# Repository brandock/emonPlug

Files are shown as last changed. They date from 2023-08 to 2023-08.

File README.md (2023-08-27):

# emonPlug Overview
OpenEnergyMonitor-compatible energy monitoring US plug. 

emonPlug is an energy monitoring transmitter unit that can monitor AC electrical consumption of one appliance connected to its NEMA 5-15R receptacle. 

emonPlug is designed to be used together with an emonBase web-connected base station from OpenEnergyMonitor. It can be thought of as an emonTx+emonVs for monitoring one appliance.

Make sure to read the warning and disclaimer below before starting any work on emonPlug assembly or use. 

# emonPlug Architecture
emonPlug uses a CT to perform non-invasive current monitoring, similar to emonTx from OpenEnergyMonitor. https://docs.openenergymonitor.org/emontx3/index.html

It uses a voltage transformer for voltage monitoring and includes a built-in power supply, similar to emonVs from OpenEnergyMonitor. https://docs.openenergymonitor.org/emontx4/voltage_sensors.html

It is firmware compatible with emonTx3 (with appropriate calibration settings). emonPlug-specific firmware, based on the emonTx3 firmware, is provided in this repository.

To use emonTx34_CM firmware change the following settings:

float vCal_USA = 111.686;  
float i1Cal = 14.68;                                       
float i1Lead = 7.6;

bool  USA=true;

The emonPlug-specific firmware omits CTs 2, 3, and 4 and provides a more detailed packet for CT1: Vrms, Irms, PowerFactor, Frequency, LogPeriod, RealPower, ApparentPower, WattHours.

# emonPlug Parts
The CT is an AC1015 from Talema Group. It is rated to 15A with 1000:1 turn ratio. https://talema.com/wp-content/uploads/datasheets/AC.pdf

The voltage transformer is the ZMPT101B. This is the same transformer used in the emonVs. The current emonPlug is US-specific, so the 3x10K, 1/4W current-limiting resistors are designed to maximize the waveform of 120V AC. More resistance, more power dissipation, and a different burden resistor would be necessary for anyone modifying emonPlug for use with 240V AC outside the US.

emonPlug uses the Polycase PM2425 AC wall plug enclosure with US 15 AMP 120 VAC plug configuration. https://www.polycase.com/pm2425.

The emonPlug MCU is the Microchip ATMega328 and the radio is the HopeRF RFM69CW, similar to emonTx3.

# emonPlug Photos

emonCMS_output

pm2425




# Warning and Disclaimer
Make sure to read this disclaimer before starting any work on emonPlug assembly or use. Credit to Felix Rusu of LowPowerLab for the wise wording of this advice and disclaimer.

emonPlug is isolated from mains electricity via the RECOM PSU (3kV isolation). Additional safety devices in the emonPlug include a current limiting fuse and a MOV (metal oxide varistor) device to help protect against transients.

Electricity WARNING: whenever you touch anything that is or was connected to mains voltages you have to really know what you are doing, otherwise you may shock yourself to shivers. If you are not 100% sure, do yourself a favor and don’t touch anything. ATX power supplies, TVs, CRT/LCD monitors, among most other high voltage devices contain very large capacitors that can hold lethal charges that may or may not discharge after the device is unplugged. You should discharge these caps before touching the circuit.

You should not attempt to assemble or use an emonPlug if you are not familiar with mains wiring! Mains voltage can cause a fatal shock or start a fire when used improperly or negligently! Please consult this electrical safety handbook to understand how you can protect yourself and your equipment from electrical shock.

The emonPlug is not an end consumer product but an open-source design that requires assembly/soldering and is intended for users comfortable/qualified to assemble it. Certain parts are polarized and require proper orientation before soldering otherwise emonPlug may malfunction or not work.
emonPlug also requires programming prior to it being functional. The designer of emonPlug is not liable for how the end user decides to assemble or use and customize the sample firmware code. The information and sample code is meant as an educational resource only, to help guide the end user with assembly and better understand how emonPlug can operate. The end user is fully responsible to ensure the final product will be electrically safe to operate.
Although as a whole, emonPlug is not UL/CSA/CE certified. It uses a certified power supply. However emonPlug comes with NO GUARANTEES expressed or implied and the designer is not liable for any injuries or damage caused by improper assembly or use of emonPlug. It may be against code to install non UL certified equipment in your area, so you are responsible to make sure you are compliant or take any risks on your own. If you do not agree or understand the terms of this disclaimer you should not use emonPlug. Use it at your own risk.

# Alternatives to emonPlug
Switchbot Mini Plug with Tasmota is a good way to monitor energy consumption via emonBase through MQTT. https://templates.blakadder.com/switchbot_plugmini_W1901400.html
The Tasmota firmware can be loaded without disassembling the unit. https://github.com/kendallgoto/switchbota/

Felix Rusu once modified a Kill-a-Watt to transmit readings to an emonBase. https://lowpowerlab.com/tag/arduino/

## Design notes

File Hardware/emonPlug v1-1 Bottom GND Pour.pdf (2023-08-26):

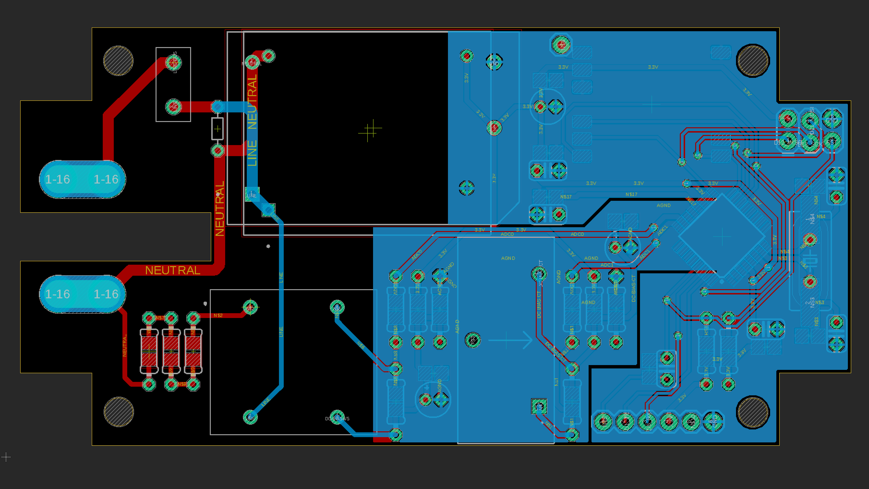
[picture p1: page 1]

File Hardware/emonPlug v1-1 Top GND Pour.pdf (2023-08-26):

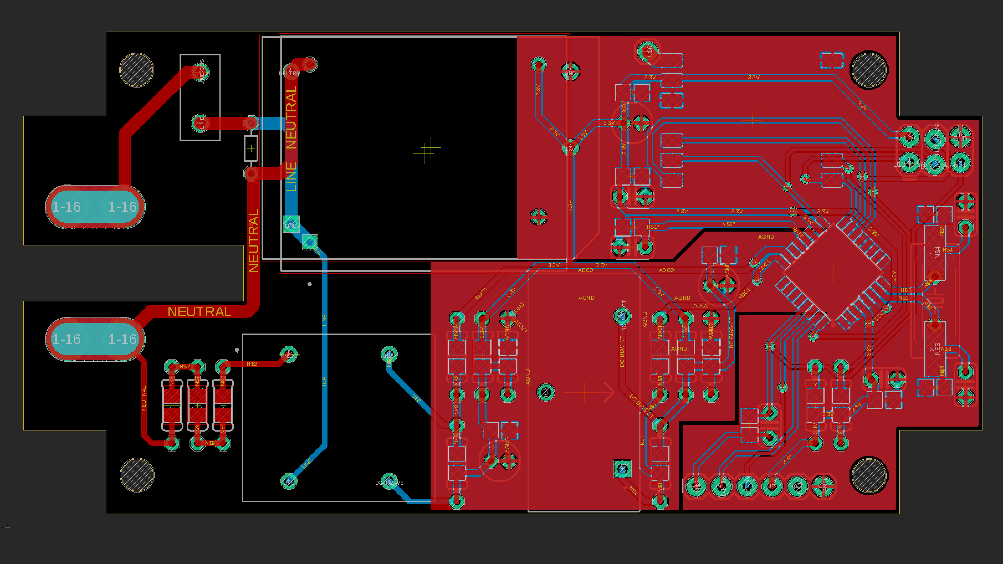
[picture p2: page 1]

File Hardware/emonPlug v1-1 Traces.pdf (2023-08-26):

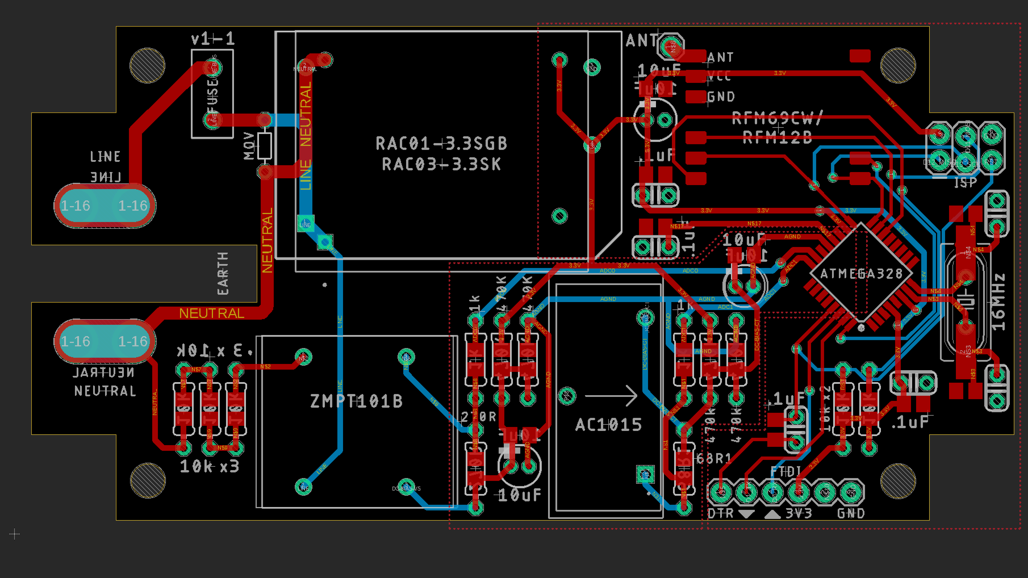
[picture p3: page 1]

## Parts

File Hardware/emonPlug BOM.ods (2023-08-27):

Parts Available from Digikey
Manufacturer Part Number | Manufacturer Name | Description | QTY | Digi-Key Part Number 1 | Unit Price USD | Extended Price USD | Customer Reference
LFXTAL027945BULK | IQD Frequency Products | CRYSTAL 16.0000MHZ 22PF TH | 1 | 1923-1788-ND | $0.50 | $0.50 | Crystal
C315C220J2G5TA7303 | KEMET | CAP CER 22PF 200V C0G/NP0 RADIAL | 2 | 399-C315C220J2G5TA7303CT-ND | $0.41 | $0.82 | Crystal load caps
RSTA 1-BULK SHORT | Bel Fuse Inc. | FUSE BRD MT 1A 250VAC 63VDC RAD | 1 | 507-RSTA1-BULKSHORT-ND | $0.43 | $0.43 | Fuse
MOV-07D391KTR | Bourns Inc. | VARISTOR 390V 1.2KA DISC 7MM | 1 | 118-MOV-07D391KTRCT-ND | $0.34 | $0.34 | MOV
AC1015 | Talema Group LLC | CURR SENSE XFMR 15A T/H | 1 | 1295-1097-ND | $5.58 | $5.58 | CT
RAC03-3.3SK | Recom Power | AC/DC CONVERTER 3.3V 3W | 1 | 945-3440-ND | $7.54 | $7.54 | PSU
RNF14BTE10K0 | Stackpole Electronics Inc | RES 10K OHM 0.1% 1/4W AXIAL | 1 | RNF14BTE10K0CT-ND | $0.61 | $0.61 | current-limiting resistors
YR1B475KCC | TE Connectivity Passive Product | RES 475K OHM 0.1% 1/4W AXIAL | 4 | 1712-YR1B475KCCCT-ND | $0.63 | $2.52 | voltage dividers for DC bias
YR1B68R1CC | TE Connectivity Passive Product | RES 68.1 OHM 0.1% 1/4W AXIAL | 1 | 1712-YR1B68R1CCCT-ND | $0.63 | $0.63 | CT burden
MFP-25BRD52-270R | YAGEO | RES 270 OHM 0.1% 1/4W AXIAL | 1 | 270ADCT-ND | $0.71 | $0.71 | Voltage sampling burden
CF14JT1K00 | Stackpole Electronics Inc | RES 1K OHM 5% 1/4W AXIAL | 2 | CF14JT1K00CT-ND | $0.10 | $0.20 | ADC-protecting resistors
CF14JT10K0 | Stackpole Electronics Inc | RES 10K OHM 5% 1/4W AXIAL | 2 | CF14JT10K0CT-ND | $0.10 | $0.20 | SEL and RST Pullups
640905-2 | TE Connectivity AMP Connectors | CONN QC RCPT 14-16AWG 0.250 | 2 | A0904CT-ND | $0.47 | $0.94 | AMP connectors for Polycase prongs
C320C104K5R5TA7317 | KEMET | CAP CER 0.1UF 50V X7R RADIAL | 4 | 399-14036-1-ND | $0.21 | $0.84 | .1uf caps for decoupling and autoreset
ATMEGA328-AU | Microchip Technology | IC MCU 8BIT 32KB FLASH 32TQFP | 1 | ATMEGA328-AU-ND | $2.42 | $2.42 | MCU
EEA-GA1C100H | Panasonic Electronic Components | CAP ALUM 10UF 20% 16V RADIAL | 3 | P15787CT-ND | $0.25 | $0.75 | for PSU, transceiver, and DC biases
68602-406HLF | Amphenol ICC (FCI) | CONN HEADER VERT 6POS 2.54MM | 1 | 609-4934-ND | $0.27 | $0.27 | ISP Header
61300611121 | Würth Elektronik | CONN HEADER VERT 6POS 2.54MM | 1 | 732-5319-ND | $0.35 | $0.35 | Serial programming header
738W-X2/03 | Qualtek | PWR ENT RCPT NEMA5-15 PANEL QC | 1 | Q227-ND | $1.32 | $1.32 | Outlet receptacle
Other Parts
 | Binneker | 14 Gauge Silicone 14 AWG Stranded Wire 400 Strands Tinned Copper | 3 | https://www.amazon.com/dp/B07X3FZ31B/ref=dp_iou_view_item?ie=UTF8&th=1 | $1.00 | $1.00 | Mains outlet hookup wire
PM2425T13XNT | Polycase | PM2425 AC Wall Plug | 1 | https://www.polycase.com/pm2425 | $6.09 | $6.09 | Wall plug enclosure
RFM69CW 433mhz | HopeRF | RFM69CW 433mhz transceiver - 13dBm transmit power | 1 | https://lowpowerlab.com/shop/product/155 | $5.95 | $5.95 | Transceiver
4394 | Adafruit | Simple spring antenna 433MHz | 1 | https://www.adafruit.com/product/4394 | $0.95 | $0.95 | Transceiver antenna (or use a wire whip)
 |  |  |  |  |  | $40.96

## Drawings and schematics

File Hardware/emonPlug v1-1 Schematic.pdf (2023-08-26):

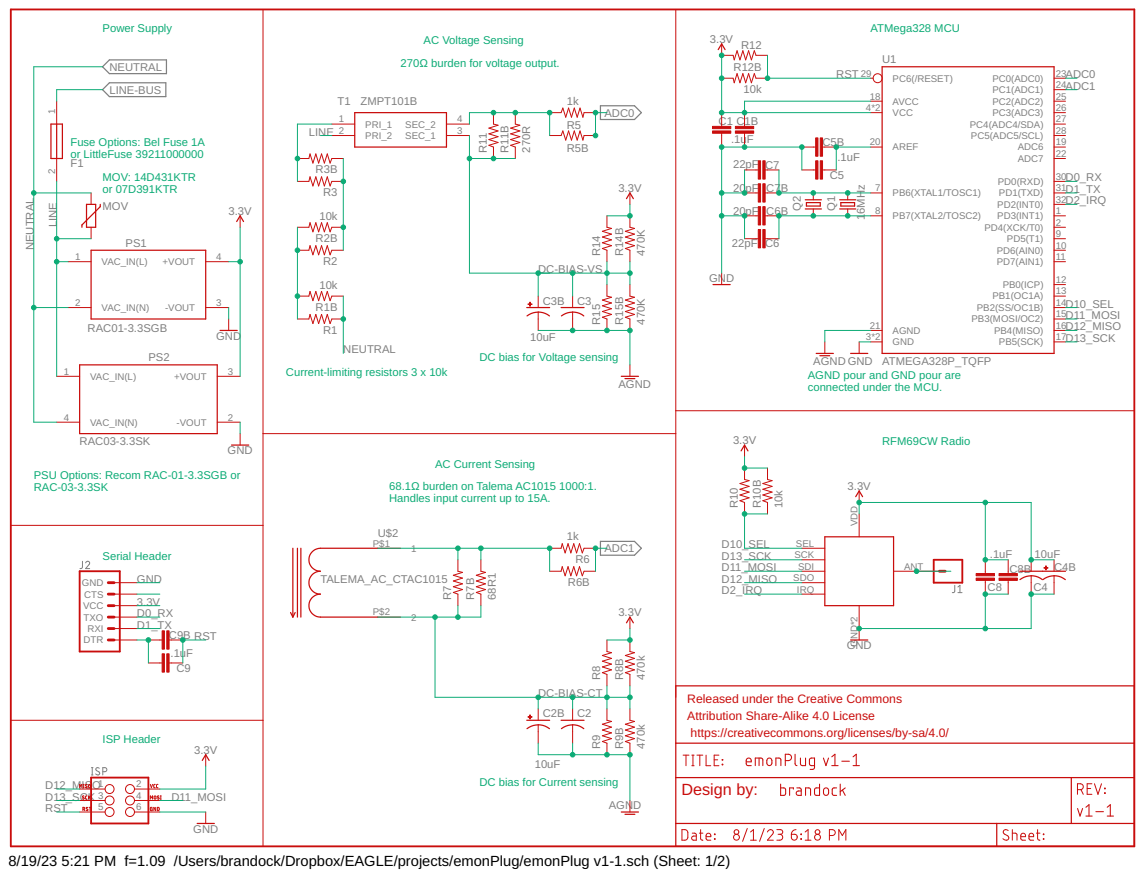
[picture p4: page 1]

AC Voltage Sensing
270Ω burden for voltage output.

DC bias for Voltage sensing

AGND GND
AGND pour and GND pour are
connected under the MCU.

68.1Ω burden on Talema AC1015 1000:1. Handles input current up to 15A. AC Current Sensing

PSU Options: Recom RAC-01-3.3SGB or RAC-03-3.3SK

Released under the Creative Commons
Attribution Share-Alike 4.0 License
https://creativecommons.org/licenses/by-sa/4.0/

DC bias for Current sensing

8/19/23 5:21 PM f=1.09 /Users/brandock/Dropbox/EAGLE/projects/emonPlug/emonPlug v1-1.sch (Sheet: 1/2)

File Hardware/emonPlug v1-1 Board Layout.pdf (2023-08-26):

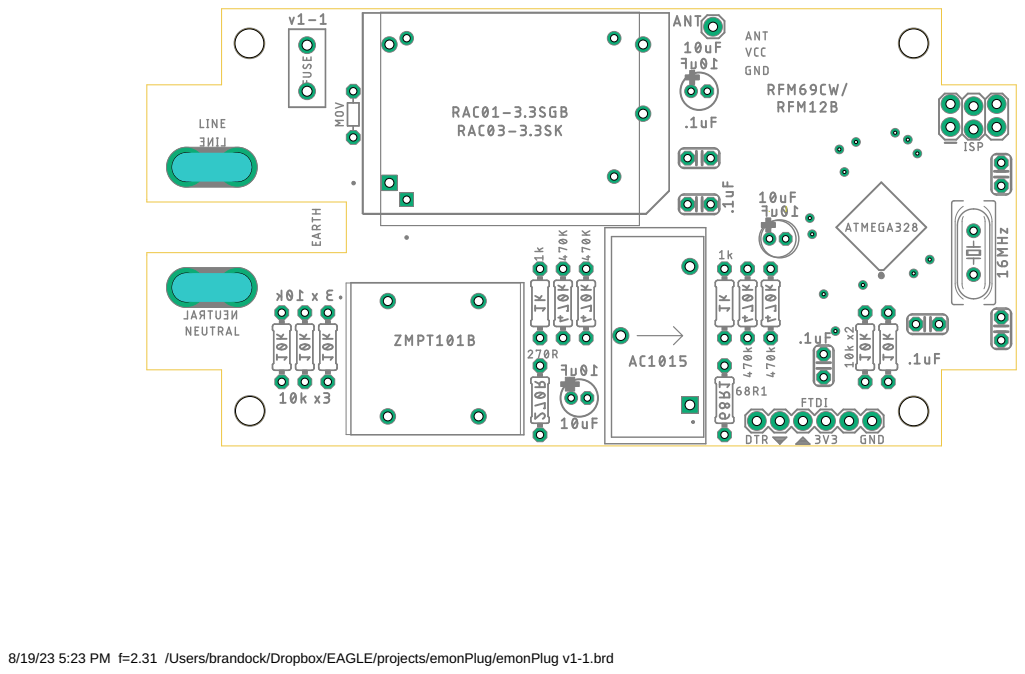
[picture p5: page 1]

8/19/23 5:23 PM f=2.31 /Users/brandock/Dropbox/EAGLE/projects/emonPlug/emonPlug v1-1.brd

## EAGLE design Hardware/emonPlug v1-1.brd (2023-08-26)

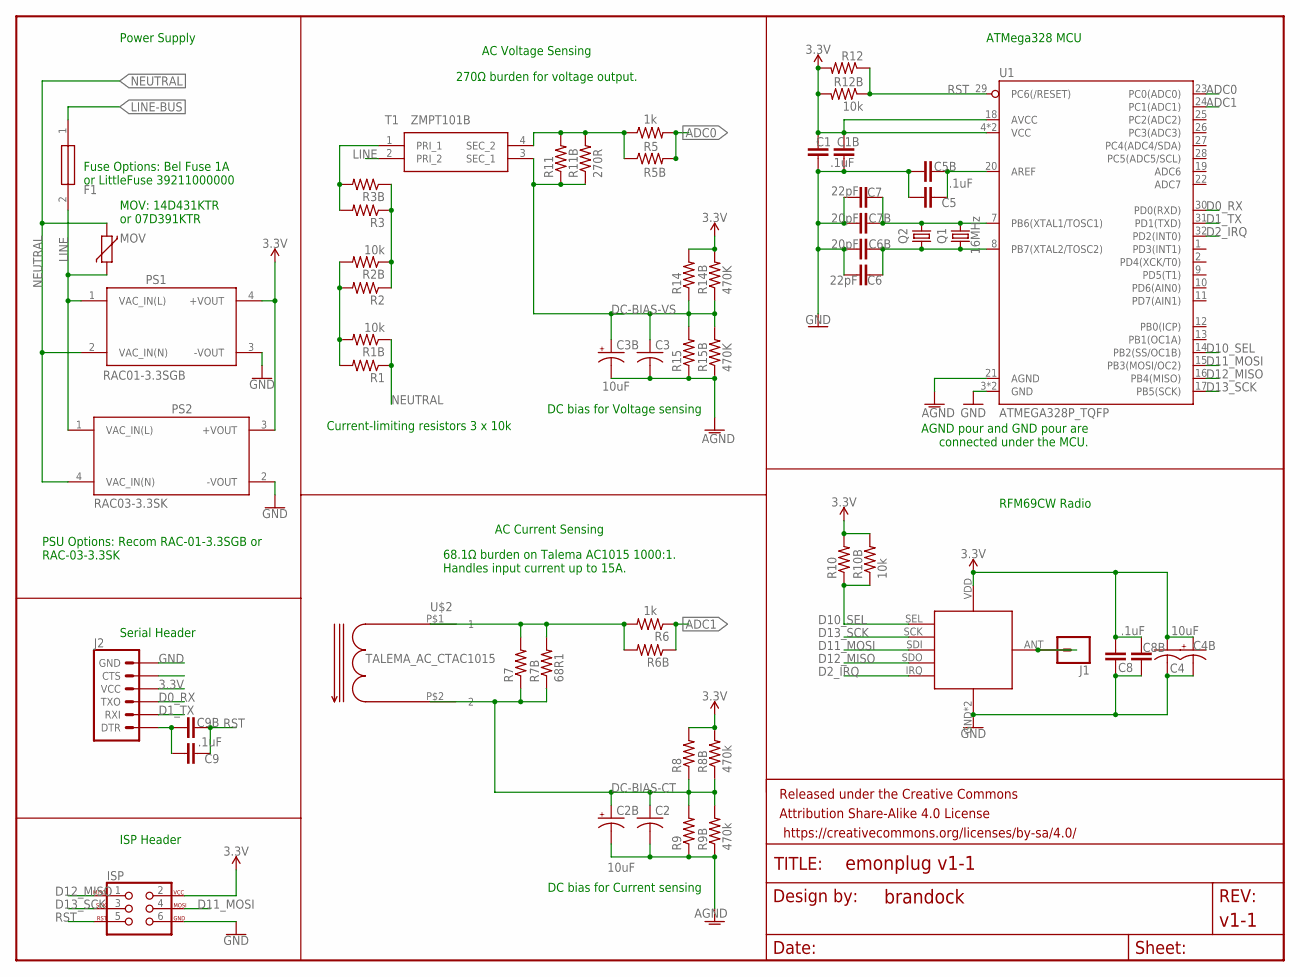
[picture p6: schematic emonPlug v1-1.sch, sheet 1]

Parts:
C1, C5, C8, C9: .1uF; C0805
C1B, C5B, C8B, C9B: .1uF; C025-024X044
C2, C3: C-USC0805; C0805
C2B, C3B, C4B: 10uF; E1,8-4
C4: 10uF; C0805
C6, C7: 22pF; C0805
C6B, C7B: 20pF; C025-024X044
F1: 39211000000
FRAME1: FRAME-LETTER; CREATIVE_COMMONS
ISP: AVR_SPI_PROG_3X22X3_LOCK; 2X3_LOCK
J1: CONN_01; 1X01
J2: 6_PIN_SERIAL_TARGET_SILK; 1X06
MOV: VARISTOR-5; R-5
PS1: RAC01-3.3SGB; CONV_RAC01-3.3SGB
PS2: RAC03-3.3SK; CONV_RAC03-3.3SK
Q1: 16MHz; HC49/S-NO-SILK
Q2: CRYSTALHC49UP; HC49UP
R1, R2, R3, R6, R7, R8, R9, R10, R11, R12, R14, R15: R-US_R0805; R0805
R1B, R2B, R10B, R12B: 10k; 0204/7
R3B, R5B: R-US_0204/7; 0204/7
R5: 1k; R0805
R6B: 1k; 0204/7
R7B: 68R1; 0204/7
R8B, R9B: 470k; 0204/7
R11B: 270R; 0204/7
R14B, R15B: 470K; 0204/7
T1: ZMPT101B
U1: ATMEGA328P_TQFP; TQFP32-08
U$2: TALEMA_AC_CTAC1015; AC1005-1020
U$3: RFM12B_MINPADS; RFM12B-MINPADS

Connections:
3.3V: C1.2, C1B.1, C4.1, C4B.+, C8.1, C8B.1, ISP.2, J2.4 (VCC), PS1.4 (+VOUT), PS2.3 (+VOUT), R8.2, R8B.2, R10.2, R10B.2, R12.2, R12B.2, R14.2, R14B.2, U1.4 (VCC), U1.6 (VCC), U1.18 (AVCC), U$3.VDD
ADC0: R5.2, R5B.2, U1.23 (PC0(ADC0))
ADC1: R6.1, R6B.1, U1.24 (PC1(ADC1))
AGND: C2.2, C2B.-, C3.2, C3B.-, R9.1, R9B.1, R15.1, R15B.1, U1.21 (AGND)
D0_RX: J2.3 (TXO), U1.30 (PD0(RXD))
D1_TX: J2.2 (RXI), U1.31 (PD1(TXD))
D2_IRQ: U1.32 (PD2(INT0)), U$3.IRQ
D10_SEL: R10.1, R10B.1, U1.14 (PB2(SS/OC1B)), U$3.SEL
D11_MOSI: ISP.4, U1.15 (PB3(MOSI/OC2)), U$3.SDI (SDI/MOSI)
D12_MISO: ISP.1, U1.16 (PB4(MISO)), U$3.SDO (SDO/MISO)
D13_SCK: ISP.3, U1.17 (PB5(SCK)), U$3.SCK
DC-BIAS-CT: C2.1, C2B.+, R7.1, R7B.1, R8.1, R8B.1, R9.2, R9B.2, U$2.P$2 (2)
DC-BIAS-VS: C3.1, C3B.+, R11.1, R11B.1, R14.1, R14B.1, R15.2, R15B.2, T1.3 (SEC_1)
GND: C1.1, C1B.2, C4.2, C4B.-, C5.1, C5B.1, C6.2, C6B.2, C7.2, C7B.2, C8.2, C8B.2, ISP.6, J2.6 (GND), PS1.3 (-VOUT), PS2.2 (-VOUT), U1.3 (GND), U1.5 (GND), U$3.GND, U$3.GND2 (GND)
LINE: F1.2, MOV.1, PS1.1 (VAC_IN(L)), PS2.1 (VAC_IN(L)), T1.2 (PRI_2)
LINE-BUS: F1.1
unnamed: R6.2, R6B.2, R7.2, R7B.2, U$2.P$1 (1)
unnamed: R3.2, R3B.2, T1.1 (PRI_1)
unnamed: C7.1, C7B.1, Q1.2, Q2.2, U1.7 (PB6(XTAL1/TOSC1))
unnamed: C6.1, C6B.1, Q1.1, Q2.1, U1.8 (PB7(XTAL2/TOSC2))
unnamed: C9.1, C9B.1, J2.1 (DTR)
unnamed: J1.1, U$3.ANT
unnamed: R1.2, R1B.2, R2.2, R2B.2
unnamed: R5.1, R5B.1, R11.2, R11B.2, T1.4 (SEC_2)
unnamed: R2.1, R2B.1, R3.1, R3B.1
unnamed: C5.2, C5B.2, U1.20 (AREF)
NEUTRAL: MOV.2, PS1.2 (VAC_IN(N)), PS2.4 (VAC_IN(N)), R1.1, R1B.1
RST: C9.2, C9B.2, ISP.5, R12.1, R12B.1, U1.29 (PC6(/RESET))

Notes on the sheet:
RFM69CW Radio
ATMega328 MCU
DC bias for Voltage sensing
270Ω burden for voltage output.
Current-limiting resistors 3 x 10k
AC Voltage Sensing
68.1Ω burden on Talema AC1015 1000:1. Handles input current up to 15A.
AC Current Sensing
Fuse Options: Bel Fuse 1A or LittleFuse 39211000000
MOV: 14D431KTR or 07D391KTR
PSU Options: Recom RAC-01-3.3SGB or RAC-03-3.3SK
Power Supply
DC bias for Current sensing
Serial Header
ISP Header
AGND pour and GND pour are connected under the MCU.

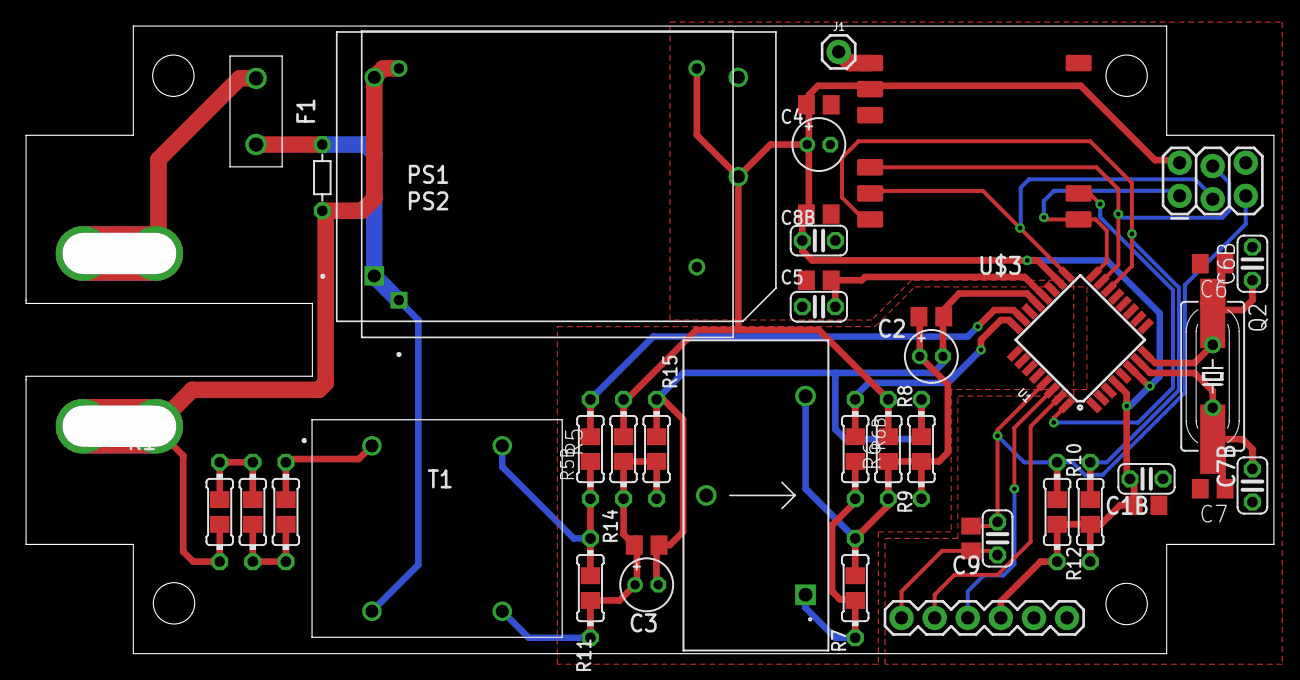
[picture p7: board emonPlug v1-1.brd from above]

Board: 2 copper layers, 95.8 x 48.2 mm, 58 parts (0 on the bottom side), 27 nets.

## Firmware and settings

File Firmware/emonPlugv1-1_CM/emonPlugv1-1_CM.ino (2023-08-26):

/* emonPlug v1-1 Continuous Sampling
 * Brandon Baldock August 2023
 * Firmware for version v1-1 of emonPlug
 * 
 * This is a modified version of emonTx34_CM by Robin Emley, Robert Wall, and Trystan Lea.
 * 
 * It sends MSG,Vrms,Irms,PowerFactor,Frequency,LogPeriod,RealPower,ApparentPower,WattHours.
 * 
 * The following entry is needed for emonHub.

[[28]]
  nodename = emonPlugCM
  [[[rx]]]
    names =  MSG,Vrms,Irms,PowerFactor,Frequency,LogPeriod,RealPower,ApparentPower,WattHours
    datacodes = L,h,h,h,h,h,h,h,L
    scales = 1,.01,.01,.01,.01,.01,1,1,1
    units = n,V,A,n,Hz,s,W,VA,Wh

 * The changes to the original emonTx34 sketch are as follows.
 * Changed default node from 15 to 28.
 * Changed network group to 100: byte networkGroup = 100;  
 * 
 * sendWithRetry(5, ...) -- my basestation is not typically 5, so I just broadcast to 0
        //radio.send(0, (const void*)(&emontx), sizeof(emontx));
        radio.sendWithRetry(0, (const void*)(&emontx), sizeof(emontx), 2, 30);
 * 
 * Set the default for the USA boolean to True. bool  USA=true;
 * 
 * Changed vCal_USA, i1Cal and i1Lead as follows
 *  float vCal_USA = 111.686;  
 *  float i1Cal = 14.68;                                       
 *  float i1Lead = 7.6;                                       
 *  ...
 *  float assumedVrms = 120.00;                               // Assumed Vrms when no a.c. is detected
 *  float lineFreq = 60; 
 *  
 * Added this to list_calibration in emonTx34_CM_config: if (USA) Serial.print(F("USA mode enabled. vCal_USA = ")); Serial.println(EEProm.vCal_USA); 
 * 
 * Removed all the pulse and temperature measurement code.
 * 
 * Removed CT2, CT3, and CT4, which are not present in emonPlug
 *
 * Change Log:
 * v1.0.0: First version for emonPlug, based on v2.4.0 emonTx34_CM firmware
 */

const char *firmware_version = {"1.1.0\n\r"};


#define RFM69_JEELIB_CLASSIC 1
#define RFM69_JEELIB_NATIVE 2
#define RFM69_LOW_POWER_LABS 3

#define RadioFormat RFM69_LOW_POWER_LABS

// Comment/Uncomment as applicable
#define DEBUG                                              // Debug level print out

// #define EEWL_DEBUG

#define FACTORYTESTGROUP 1                                 // Transmit the Factory Test on Grp 1 
                                                           //   to avoid interference with recorded data at power-up.
#define OFF HIGH
#define ON LOW

#define RFM69CW

#include <Arduino.h>
#include <avr/wdt.h>

#if RadioFormat == RFM69_LOW_POWER_LABS
  #include <RFM69.h>                             // RFM69 LowPowerLabs radio library
#elif RadioFormat == RFM69_JEELIB_CLASSIC
  #include <rfmTxLib.h>                          // RFM69 transmit-only library using "JeeLib RFM69 Native" message format
#elif RadioFormat == RFM69_JEELIB_NATIVE
  #include <rfm69nTxLib.h>                       // RFM69 transmit-only library using "JeeLib RFM69 Native" message format
#endif

#include <emonEProm.h>                                     // OEM EEPROM library
#include <emonLibCM.h>                                     // OEM Continuous Monitoring library

// Include emonTx34_CM_config.ino in the same directory for settings functions & data

// Radio - checks for traffic
const int busyThreshold = -97;                             // Signal level below which the radio channel is clear to transmit
const byte busyTimeout = 15;                               // Time in ms to wait for the channel to become clear, before transmitting anyway

typedef struct {
    unsigned long Msg;
    //The library functions return decimal values, so these values need to be multiplied by 100 to store and transmit, then divided by 100 in emonHub config
    int Vrms;   //Avg Vrms over the reporting period
    int IRMS1;  //Avg Irms over the reporting period
    int PF1;    //Avg power factor over the reporting period
    int Freq;   //Avg frequency of the AC power over the reporting period
    int LogPeriod; //Reporting period in seconds 
    //The library function returns integer values for the following
    int P1;       //Average real power in watts over the reporting period
    int AP1;      //Average apparent power in watts over the reporting period
    long E1; 
} PayloadTX;
PayloadTX emontx;                                                  // create a data packet for the RFM
static void showString (PGM_P s);
 
 
//---------------------------- emonTx Settings - Stored in EEPROM and shared with config.ino ------------------------------------------------
struct {
  byte RF_freq = RF69_433MHZ;                               // Frequency of radio module can be RF69_433MHZ, RF69_868MHZ or RF69_915MHZ. 
  byte networkGroup = 100;                                 // wireless network group, must be the same as emonBase / emonPi and emonGLCD. OEM default is 210
  byte  nodeID = 27;                                       // node ID for this emonTx.
  byte  rf_on = 1;                                         // RF - 0 = no RF, 1 = RF on.
  byte  rfPower = 31;                                      // 7 = -10.5 dBm, 25 = +7 dBm for RFM12B; 0 = -18 dBm, 31 = +13 dBm for RFM69CW. Default = 25 (+7 dBm)
  float vCal  = 268.97;                                    // (240V x 13) / 11.6V = 268.97 Calibration for UK AC-AC adapter 77DB-06-09
  float vCal_USA = 111.686;                                  // (120V × 13) / 12.0V = 130.0  Calibration for US AC-AC adapter 77DA-10-09 
  float assumedVrms = 120.00;                               // Assumed Vrms when no a.c. is detected
  float lineFreq = 60;                                     // Line Frequency = 50 Hz
  float i1Cal = 14.68;                                      // (100 A / 50 mA / 22 Ohm burden) = 90.9
  float i1Lead = 7.6;                                      // 4.2° phase lead
  float period = 9.85;                                     // datalogging period - should be fractionally less than the PHPFINA database period in emonCMS
  bool  showCurrents = false;                              // Print to serial voltage, current & p.f. values
  bool  json_enabled = false;                              // JSON Enabled - false = key,Value pair, true = JSON, default = false: Key,Value pair.  
} EEProm;

uint16_t eepromSig = 0x0015;                               // oemEProm signature - see oemEProm Library documentation for details.

#ifdef EEWL_DEBUG
  extern EEWL EVmem;
#endif

#if RadioFormat == RFM69_LOW_POWER_LABS
  RFM69 radio;
#endif


bool  USA=true;

bool calibration_enable = true;                            // Enable on-line calibration when running. 
                                                           // For safety, thus MUST default to false. (Required due to faulty ESP8266 software.)

//---------------------------------CT availability status----------------------------------------
byte CT_count = 0;
bool CT1;     // Record if CT present during startup


//----------------------------------------Setup--------------------------------------------------
void setup() 
{  
  wdt_enable(WDTO_8S);
    
  // Serial---------------------------------------------------------------------------------
  Serial.begin(115200);

  // ---------------------------------------------------------------------------------------
  #ifdef DEBUG
    Serial.print(F("emonPlug Continuous Monitoring V")); Serial.write(firmware_version);
    Serial.println(F("OpenEnergyMonitor.org"));
  #else
    Serial.println(F("describe:EmonTX3CM"));
  #endif
  
  #if RadioFormat == RFM69_JEELIB_CLASSIC
    EEProm.rf_on = 2;
  #endif
 
  load_config(true);                                                   // Load RF config from EEPROM (if any exists)
  
  if (EEProm.rf_on)
  {
    #ifdef DEBUG
      #ifdef RFM12B
      Serial.print(F("RFM12B "));
      #endif
      #ifdef RFM69CW
      Serial.print(F("RFM69CW "));
      #endif
      Serial.print(F(" Freq: "));
      if (EEProm.RF_freq == RF69_433MHZ) Serial.print(F("433MHz"));
      if (EEProm.RF_freq == RF69_868MHZ) Serial.print(F("868MHz"));
      if (EEProm.RF_freq == RF69_915MHZ) Serial.print(F("915MHz"));
      Serial.print(F(" Group: ")); Serial.print(EEProm.networkGroup);
      Serial.print(F(" Node: ")); Serial.print(EEProm.nodeID);
      Serial.println(F(" "));
    #endif
  }
  

  // Check connected CT sensors ------------------------------------------------------------
  if (analogRead(1) > 0) {CT1 = 1; CT_count++;} else CT1=0;            // check to see if CT is connected to CT1 input

  // ---------------------------------------------------------------------------------------

  if (EEProm.rf_on)
  {
    Serial.println(F("Factory Test"));
    #if RadioFormat == RFM69_LOW_POWER_LABS
      radio.initialize(RF69_433MHZ,EEProm.nodeID,EEProm.networkGroup);  
      radio.encrypt("89txbe4p8aik5kt3");                                                      // initialize RFM
      radio.setPowerLevel(EEProm.rfPower);
    #else
      rfm_init();                                                        // initialize RFM
    #endif
    for (int i=10; i>=0; i--)                                          // Send RF test sequence using test Group (for factory testing)
    {
      emontx.P1=i;
      #if RadioFormat == RFM69_LOW_POWER_LABS
        radio.send(1, (const void*)(&emontx), sizeof(emontx));  
        showString(PSTR(" -> "));   
        Serial.print((word) sizeof(emontx));    
        showString(PSTR(" b\n"));
      #else
        PayloadTX tmp = emontx;
        if (EEProm.rf_on == 2) {
            byte WHITENING = 0x55;
            for (byte i = 0, *p = (byte *)&tmp; i < sizeof tmp; i++, p++)
                *p ^= (byte)WHITENING;
        }
        rfm_send((byte *)&tmp, sizeof(tmp), FACTORYTESTGROUP, EEProm.nodeID, EEProm.RF_freq, EEProm.rfPower, busyThreshold, busyTimeout);
      #endif
      delay(100);
    }
    #if RadioFormat == RFM69_LOW_POWER_LABS
      radio.sleep();
    #endif
    emontx.P1=0;
    delay(EEProm.nodeID * 20);                                 // try to avoid r.f. collisions at start-up
  }
  
  // ---------------------------------------------------------------------------------------
  #ifdef DEBUG
    if (CT_count==0) {
      Serial.println(F("NO CT's detected"));
    } else {
      if (CT1) { Serial.print(F("CT1 detected, i1Cal:")); Serial.println(EEProm.i1Cal); }
    }
    delay(200);
  #endif

#ifdef EEWL_DEBUG
  Serial.print("End of mem=");Serial.print(E2END);
  Serial.print("  Avail mem=");Serial.print((E2END>>2) * 3);
  Serial.print("  Start addr=");Serial.print(E2END - (((E2END>>2) * 3) / (sizeof(mem)+1))*(sizeof(mem)+1));
  Serial.print("  Num blocks=");Serial.println(((E2END>>2) * 3) / 21);
  EVmem.dump_buffer();
#endif

  // ----------------------------------------------------------------------------
  // EmonLibCM config
  // ----------------------------------------------------------------------------
  EmonLibCM_SetADC_VChannel(0, EEProm.vCal);                           // ADC Input channel, voltage calibration - for Ideal UK Adapter = 268.97
  if (USA) EmonLibCM_SetADC_VChannel(0, EEProm.vCal_USA);              // ADC Input channel, voltage calibration - for US AC-AC adapter 77DA-10-09
  EmonLibCM_SetADC_IChannel(1, EEProm.i1Cal, EEProm.i1Lead);           // ADC Input channel, current calibration, phase calibration
  EmonLibCM_ADCCal(3.3);                                               // ADC Reference voltage, (3.3 V for emonTx,  5.0 V for Arduino)
  if (USA) EmonLibCM_cycles_per_second(60);                            // mains frequency 60Hz
  EmonLibCM_datalog_period(EEProm.period);                             // period of readings in seconds - normal value for emoncms.org  
  EmonLibCM_setAssumedVrms(EEProm.assumedVrms);

#ifdef EEWL_DEBUG
  EVmem.dump_control();
  EVmem.dump_buffer();  
#endif
  
  EmonLibCM_Init();                                                    // Start continuous monitoring.
  emontx.Msg = 0;

  long e0=0, e1=0, e2=0, e3=0;
  unsigned long p=0;
  recoverEValues(&e0,&e1,&e2,&e3,&p);
  EmonLibCM_setWattHour(0, e0);

  // Speed up startup by making first reading 2s
  EmonLibCM_datalog_period(2.0);
}

void loop()             
{
  getSettings();
  
  if (EmonLibCM_Ready())   
  {
    #ifdef DEBUG
    if (emontx.Msg==0) 
    {

      EmonLibCM_datalog_period(EEProm.period); 
      if (EmonLibCM_acPresent())
        Serial.println(F("AC present - Real Power calc enabled"));
      else
      {
        Serial.print(F("AC missing - Apparent Power calc enabled, assuming ")); Serial.print(EEProm.assumedVrms); Serial.println(F(" V"));
      }
    }
    delay(5);
    #endif

    emontx.Msg++;

    if (EmonLibCM_acPresent()) {
      emontx.Vrms = EmonLibCM_getVrms() * 100;
    } else {
      emontx.Vrms = EmonLibCM_getAssumedVrms() * 100;
    }
    
    emontx.IRMS1 = EmonLibCM_getIrms(0) * 100;
    emontx.PF1 = EmonLibCM_getPF(0) * 100;

    emontx.Freq = EmonLibCM_getLineFrequency() * 100;
    emontx.LogPeriod = EmonLibCM_getDatalog_period() * 100;
    
    emontx.P1 = EmonLibCM_getRealPower(0); 
    emontx.AP1 = EmonLibCM_getApparentPower(0);
    emontx.E1 = EmonLibCM_getWattHour(0); 
   
    if (EEProm.rf_on)
    {
      #if RadioFormat == RFM69_LOW_POWER_LABS
        radio.sendWithRetry(0, (const void*)(&emontx), sizeof(emontx), 2, 30);
        //radio.sendWithRetry(5, (const void*)(&emontx), sizeof(emontx));
        //radio.send(0, (const void*)(&emontx), sizeof(emontx));
        radio.sleep();
      #else
        PayloadTX tmp = emontx;
        if (EEProm.rf_on == 2) {
            byte WHITENING = 0x55;
            for (byte i = 0, *p = (byte *)&tmp; i < sizeof tmp; i++, p++)
                *p ^= (byte)WHITENING;
        }
        rfm_send((byte *)&tmp, sizeof(tmp), EEProm.networkGroup, EEProm.nodeID, EEProm.RF_freq, EEProm.rfPower, busyThreshold, busyTimeout);     //send data
      #endif
      
      delay(50);
    }

    if (EEProm.json_enabled) {
      // ---------------------------------------------------------------------
      // JSON Format
      // ---------------------------------------------------------------------
      Serial.print(F("{\"MSG\":")); Serial.print(emontx.Msg);
      Serial.print(F(",\"Vrms\":")); Serial.print(emontx.Vrms*0.01);

      if (CT1) { Serial.print(F(",\"P1\":")); Serial.print(emontx.P1); }
      Serial.println(F("}"));
      delay(60);
      
    } else {
  
      // ---------------------------------------------------------------------
      // Key:Value format, used by EmonESP & emonhub EmonHubOEMInterfacer
      // ---------------------------------------------------------------------
      Serial.print(F("MSG:")); Serial.print(emontx.Msg);
      Serial.print(F(",Vrms:")); Serial.print(emontx.Vrms*0.01);
      
      if (CT1) { Serial.print(F(",P1:")); Serial.print(emontx.P1); }        
      if (CT1) { Serial.print(F(",E1:")); Serial.print(emontx.E1); }

      if (!EEProm.showCurrents) {
        Serial.println();
        delay(40);
      } else {
        // to show voltage, current & power factor for calibration:
        Serial.print(F(",I1:")); Serial.print(EmonLibCM_getIrms(EmonLibCM_getLogicalChannel(1)),3);
        Serial.print(F(",pf1:")); Serial.println(EmonLibCM_getPF(EmonLibCM_getLogicalChannel(1)),4);
         delay(80);
      }
    }

    // End of print out ----------------------------------------------------
    
    storeEValues(emontx.E1,0,0,0,0);  //EmonEprom will check if E1 is 200 Wh greater than the last stored value. If not, it skips this update. If so, it stores the new value. Saves on writes.
  }
  wdt_reset();
  delay(20);
}

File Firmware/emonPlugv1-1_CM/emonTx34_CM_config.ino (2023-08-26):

/*
Configuration functions for EmonTxV34CM_rfm69n.ino
*/


#include <Arduino.h>
#include <avr/pgmspace.h>
#include <EEPROM.h>
#include <emonEProm.h>

 // Available Serial Commands
const PROGMEM char helpText1[] =                                
"\n"
"Available commands:\n"
"l\t\t- list the settings\n"
"r\t\t- restore sketch defaults\n"
"s\t\t- save settings to EEPROM\n"
"v\t\t- show firmware version\n"
"z\t\t- zero energy values\n"
"x\t\t- exit, lock and continue\n"
"?\t\t- show this text again\n"
"\n"
"w<x>\t\t- turn RFM Wireless data off: x = 0, on: x = 1, RF on whitening enabled = 2\n"
"b<n>\t\t- set r.f. band n = a single numeral: 4 = 433MHz, 8 = 868MHz, 9 = 915MHz (may require hardware change)\n"
"p<nn>\t\t- set the r.f. power. nn - an integer 0 - 31 representing -18 dBm to +13 dBm. Default: 25 (+7 dBm)\n"
"g<nnn>\t- set Network Group  nnn - an integer (OEM default = 210)\n"
"n<nn>\t\t- set node ID n= an integer (standard node ids are 1..60)\n"
"\n"
"d<xx.x>\t- xx.x = a floating point number for the datalogging period\n" 
"c<n>\t\t- n = 0 for OFF, n = 1 for ON, enable voltage, current & power factor values to serial output for calibration. \n"
"j<n>\t\t- turn JSON Serial format on (1) or off (0).\n"
"f<xx>\t\t- xx = the line frequency in Hz: normally either 50 or 60\n"
"k<x> <yy.y> <zz.z>\n"
"\t\t- Calibrate an analogue input channel:\n"
"\t\t  x = a single numeral: 0 = voltage calibration, 1 = ct1 calibration, 2 = ct2 calibration, etc\n"
"\t\t  yy.y = a floating point number for the voltage/current calibration constant\n"
"\t\t  zz.z = a floating point number for the phase calibration for this c.t. (z is not needed, or ignored if supplied, when x = 0)\n"
"\t\t  e.g. k0 256.8\n"
"\t\t       k1 90.9 2.00\n"
"a<xx.x>\t- xx.x = a floating point number for the assumed voltage if no a.c. is detected\n"
;

// Used for serial configuration
char input[64];
byte idx = 0;

static void load_config(bool verbose)
{
  bool success = eepromRead(eepromSig, (byte *)&EEProm);
  if (verbose)
  {
    if (success)
      Serial.println(F("Loaded EEPROM config"));
    else
      Serial.println(F("No EEPROM config"));
    list_calibration();
  }
}

static void list_calibration(void)
{
  Serial.println(F("Settings:"));
  Serial.print(F("Band ")); 
  Serial.print(EEProm.RF_freq == RF69_433MHZ ? 433 : 
               EEProm.RF_freq == RF69_868MHZ ? 868 :
               EEProm.RF_freq == RF69_915MHZ ? 915 : 0);
  Serial.print(F(" MHz, Group ")); Serial.print(EEProm.networkGroup);
  Serial.print(F(", Node ")); Serial.print(EEProm.nodeID & 0x3F);
  Serial.print(F(", "));Serial.print(EEProm.rfPower - 18);Serial.println(F(" dBm"));
  Serial.println(F("Calibration:"));
  Serial.print(F("vCal = ")); Serial.println(EEProm.vCal);
  if (USA) Serial.print(F("USA mode enabled. vCal_USA = ")); Serial.println(EEProm.vCal_USA);
  Serial.print(F("assumedV = ")); Serial.println(EEProm.assumedVrms);
  Serial.print(F("i1Cal = ")); Serial.println(EEProm.i1Cal);
  Serial.print(F("i1Lead = ")); Serial.println(EEProm.i1Lead);
  Serial.println(EEProm.rf_on ? F("RF on"):F("RF off"));
  Serial.println(EEProm.json_enabled ? F("JSON Format on"):F("JSON Format Off"));
}

static void save_config()
{
  Serial.println(F("Saving..."));
  eepromWrite(eepromSig, (byte *)&EEProm, sizeof(EEProm));
  eepromPrint();
  Serial.println();
  Serial.println(F("Done. New config saved to EEPROM"));
}

static void wipe_eeprom(void)
{
  Serial.println(F("Resetting..."));
  
  eepromHide(eepromSig);   
  Serial.println(F("Sketch will now restart using default config."));
  delay(200);
}

void softReset(void)
{
  asm volatile ("  jmp 0");
}


int getPass(void)
{
/*
 * Get and verify the user's access code (replaces 'readString()' saves 1300 bytes)
 */

  char buf[5];
  if (Serial.readBytes(buf, 5) != 5)
    return 0;
  // Verbose
  if  (buf[0] == '+' 
    && buf[1] == '+'
    && buf[3] == '\r'
    && buf[4] == '\n')
  {
    if (buf[2] == '+')      // Verbose
    {
      calibration_enable = true;
      return 2;
    }
    else if (buf[2] == 's') //Silent
    {
      calibration_enable = true;
      return 1;
    }
  }
  return 0;
}

void handle_conf(char *input, byte len) {
  input[len] = '\0';
  int k1;
  double k2, k3;
  byte ws1, ws2, num = 1;
  char *ptr;
  
  switch (input[0]) {
    case 'a':
      if (len==3) {
        EEProm.assumedVrms = atof(input+1);
        Serial.print(F("Assumed V: "));Serial.println(EEProm.assumedVrms);
      }
      break;
    case 'b':  // set band: 4 = 433, 8 = 868, 9 = 915
      if (len==2) {
        EEProm.RF_freq = bandToFreq(atoi(input+1));
        Serial.print(EEProm.RF_freq == RF69_433MHZ ? 433 : 
                     EEProm.RF_freq == RF69_868MHZ ? 868 :
                     EEProm.RF_freq == RF69_915MHZ ? 915 : 0);
        Serial.println(F(" MHz"));
      }
      break;
    case 'c':
      /*
      * Format expected: c0 | c1
      */
      if (len==2) {
        k1 = atoi(input+1);
        switch (k1) {
          case 1 : EEProm.showCurrents = true;
            break;
          default: EEProm.showCurrents = false;
        }
      }
      break;
    case 'j':
      /*
      * Format expected: c0 | c1
      */
      if (len==2) {
        k1 = atoi(input+1);
        switch (k1) {
          case 1 : EEProm.json_enabled = true;
            break;
          default: EEProm.json_enabled = false;
        }
      }
      break;
    case 'd':
      /*  Format expected: d[x]
       * 
       * where:
       *  [x] = a floating point number for the datalogging period in s
       */
      k2 = atof(input+1);
      //EmonLibCM_datalog_period(k2); 
      //EEProm.period = k2;
      Serial.print(F("datalog period: ")); Serial.print(k2);Serial.println(F(" s"));
      break;
    case 'e':
      input[len] = '\n';
      Serial.print(input+1);
      break;
    case 'f':
      /*
      *  Format expected: f50 | f60
      */
      if (len==3) {
        k1 = atof(input+1);
        EmonLibCM_cycles_per_second(k1);
        Serial.print(F("Freq: "));Serial.println(k1);
      }
      break;
    
    case 'g':  // set network group
      EEProm.networkGroup = atoi(input+1);
      Serial.print(F("Group ")); Serial.println(EEProm.networkGroup);
      break;
      
    /* case 'i' below */
      
    case 'k':
      /*  Format expected: k[x] [y] [z]
      * 
      * where:
      *  [x] = a single numeral: 0 = voltage calibration, 1 = ct1 calibration, 2 = ct2 calibration, etc
      *  [y] = a floating point number for the voltage/current calibration constant
      *  [z] = a floating point number for the phase calibration for this c.t. (z is not needed, or ignored if supplied, when x = 0)
      * 
      * e.g. k0 256.8
      *      k1 90.9 1.7 
      * 
      * If power factor is not displayed, it is impossible to calibrate for phase errors,
      *  and the standard value of phase calibration MUST BE SENT when a current calibration is changed.
      */
      ws1 = 0;
      ws2 = 0;
      num = 1;
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

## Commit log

2023-08-26 Add Hardware directory
    [emonPlug v1-1.brd, emonPlug v1-1.sch]
2023-08-27 Add bill of materials
    [emonPlug BOM.ods]

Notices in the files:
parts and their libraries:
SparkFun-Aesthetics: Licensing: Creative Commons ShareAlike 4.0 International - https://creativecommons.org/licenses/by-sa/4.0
